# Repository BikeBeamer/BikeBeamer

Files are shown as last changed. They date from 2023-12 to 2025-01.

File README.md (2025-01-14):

# BikeBeamer

## Overview

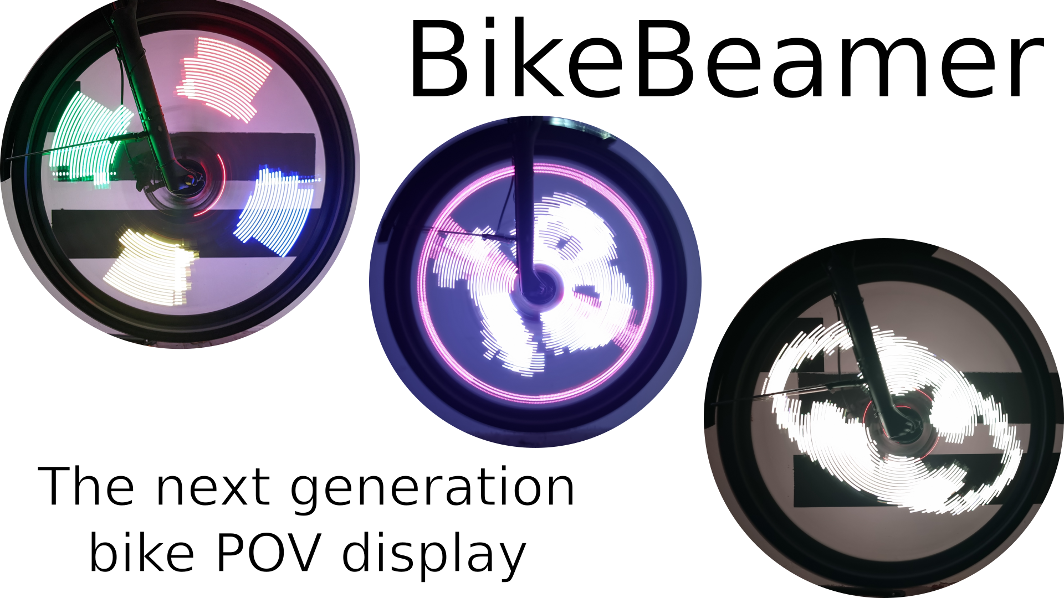
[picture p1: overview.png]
Overview image


This is my next generation of bike POV displays based on [bkpvdsply](https://github.com/locxter/bkpvdsply). With much extended functionality, a more polished design and an easier user-experience, the goal for it is to extend my capabilities and experiment with building a "real product" that lives up to the expectations one might have. Also take a look at the [project website](https://bikebeamer.com) or the launch video:

Introducing BikeBeamer - The next generation bike POV display (https://www.youtube.com/watch?v=l9HWCyl2cUI)

## Dependencies

I generally try to minimize dependencies, but I'm a one man crew and can therefore only support Debian-based Linux distributions as I'm running one myself. Anyway, you need to have the following packages installed for everything to work properly:

- Arduino IDE as a way to compile the Arduino code. Install it with `sudo apt install arduino`.
- MPU6050_tockn library for communicating with the gyroscope. Install it via the integrated library manager.
- Adafruit NeoPixel library for controlling the LEDs. Install it via the integrated library manager.

Note there is an [issue with the ESP32 core library >=3.x and the NeoPixel library when using more than 75 pixels](https://github.com/adafruit/Adafruit_NeoPixel/issues/402). There is a [forked library with a fix](https://github.com/teknynja/Adafruit_NeoPixel/tree/esp32_rmt_memory_allocation_fix_safe).

There some slight differences, depending on which major version of the Arduino IDE you are using. Extensions are not compatible with both versions. An extension is needed for uploading the data to the ESP32 LittleFS.

### Arduino IDE 1.x

Use the Arduino ESP32 LittleFS uploader for uploading the data. Install it via the [installation guide](https://github.com/lorol/arduino-esp32fs-plugin).

### Arduino IDE 2.x

Use the [Arduino LittleFS upload extension](https://github.com/earlephilhower/arduino-littlefs-upload).

## Improvements over bkpvdsply

### Hardware

- [x] Reduce the overall height to fit slimmer wheels
- [x] Rethink the mounting system to be easier for the user
- [x] FAILED: ~~Switch to a reusable cable tie alternative~~
- [x] Improve the water resistance (ideally water proof)
- [x] Make everything more balanced (equal weight distribution)
- [x] Add LED strips to both sides

### Electronics

- [x] Improve battery runtime
- [x] ABANDONED VIA SWITCH TO BATTERIES: ~~Make charging easier~~
- [x] Develop a properly sized power supply unit
- [x] Use custom-made circuit boards
- [ ] Switch to all SMT components
- [ ] Off-hand to production to a specialized vendor

### Software

- [x] Implement customizable LED strip positions (relative to control board)
- [x] Allow the rotation direction to be reversed (when the control board back faces right)
- [x] Use LED trips on both sides to display the image
- [x] Allow the image to be mirrored for the second side (useful for symbols and graphics, but not text)
- [ ] Reduce storage size of images (ideally via file compression)
- [ ] Add the ability to make animations with more than 2 images
- [x] Improve image stability (more exact rotation and speed change detection, smooth measuremets)
- [x] Implement customizable sampling threshold (allowed variation to trigger rotation detection)
- [X] Rework API with clearer endpoints
- [x] Load existing settings to UI for easier incremental changes
- [x] Store and load associative names of images for easier identification

And more to come...

## How to build it

In order to create a device able to produce such wonderful visuals, you only need rather common components (an ESP32, some LED strips, an IMU and some sort of power supply), but their combination results in this really special outcome. Everything is based on a custom PCB onto which all of the other components are soldered and which is then encased in 3D printed parts. Here's what the finished outcome should look like:

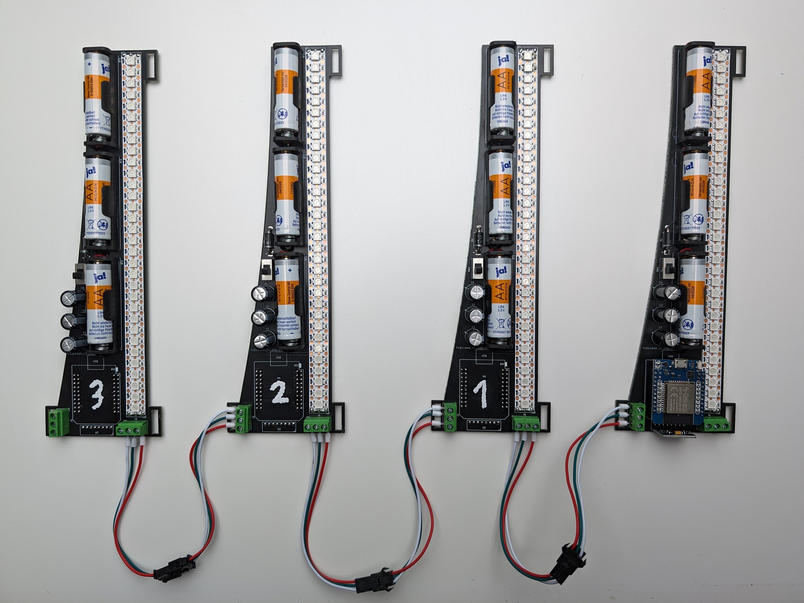
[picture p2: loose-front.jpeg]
Loose boards front


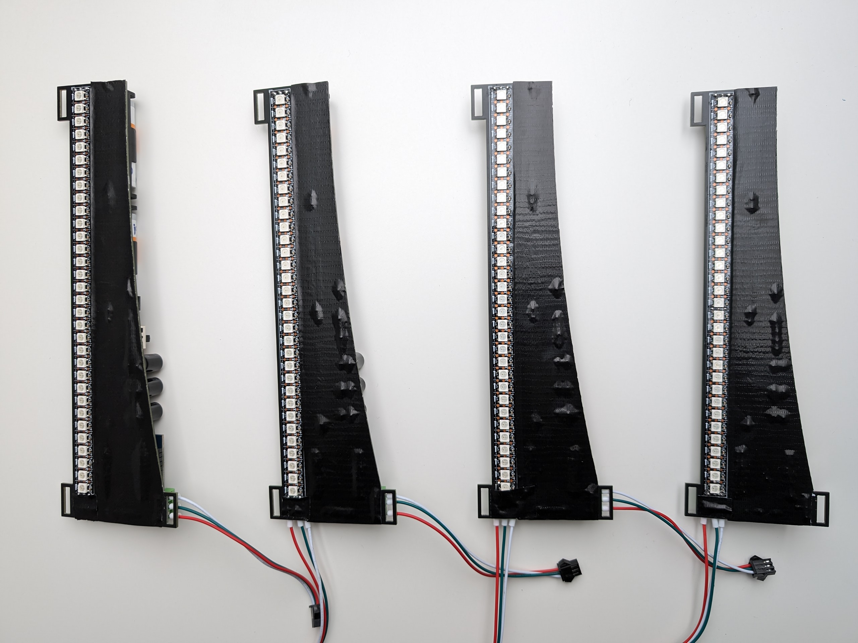
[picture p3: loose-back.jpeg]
Loose boards back


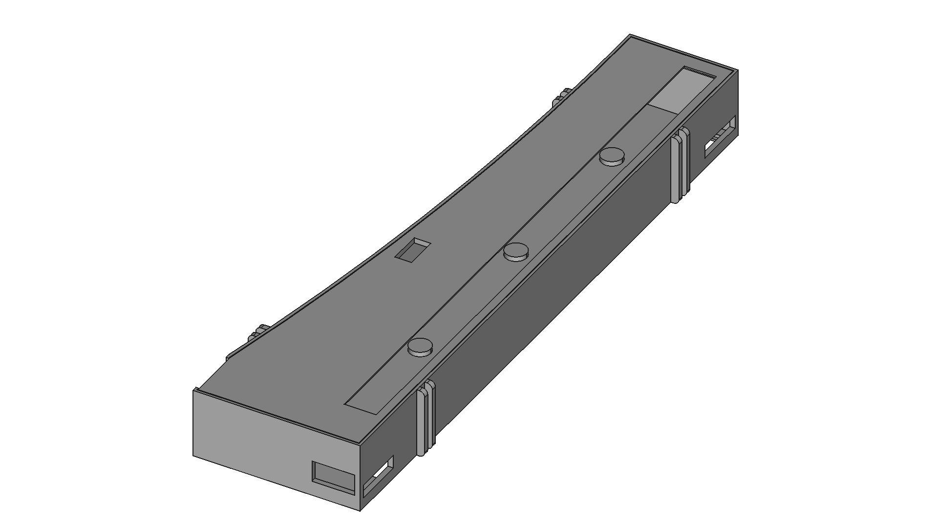
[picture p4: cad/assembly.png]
Case assembly


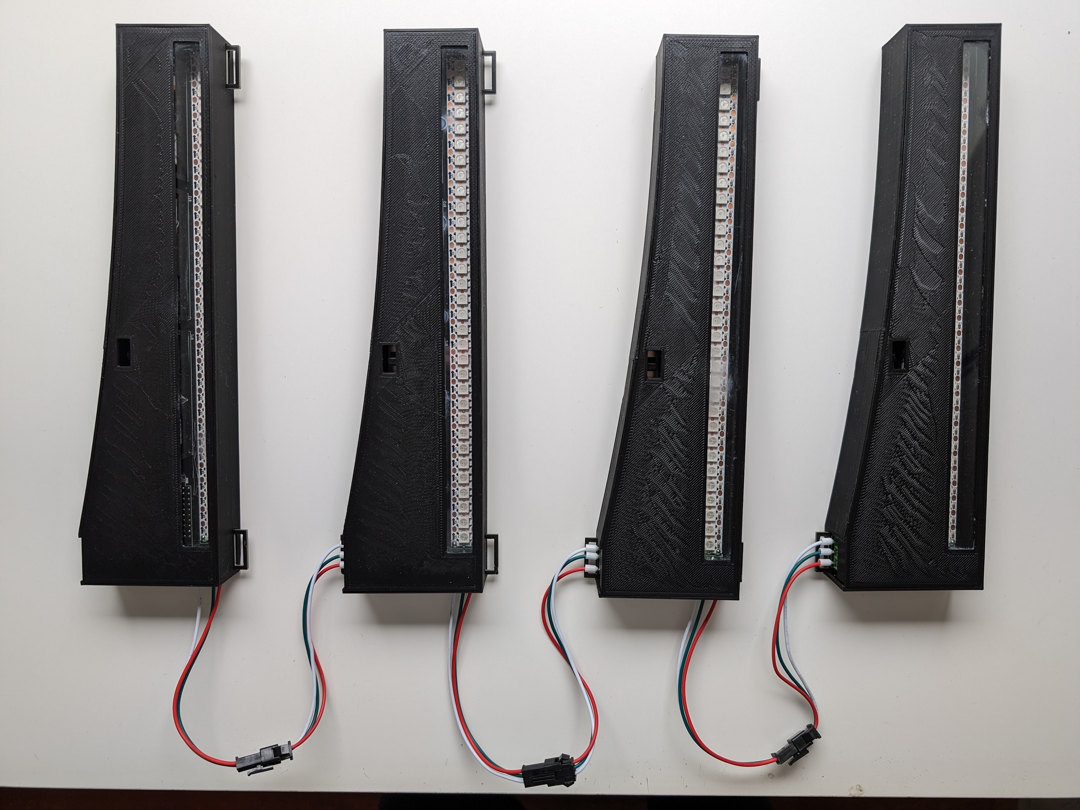
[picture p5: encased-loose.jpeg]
Encased loose boards


Even though many sequences of assembly will result in functional boards, here's how I assemble them after trying out several approaches with varying success:

1. In case you went for the cheap battery holders from Amazon, cut off the brim on the bottom, sand this side for better adhesive contact, shorten the wires and tin them in advance.
2. As always, parts should be soldered in the order of their height. So start off with cutting the LED strips to their desired length of 32 LEDs and then solder them down with the arrows facing towards the slim end of the boards from each side. It's easiest to solder one side of a strip, apply some instant glue along it's way and then solder the other one mounting it into place.
3. After that's done, continue with the diodes - be careful to install them the right way around (silver ring facing the marked direction) - and On/Off switch.
4. Now it's time install the ESP32 and IMU. Solder male headers facing down to the D1 Mini board in case not already done and then mount their female counterparts to the main PCB. You can also fill the contacts on the other boards, but that's not necessary. Then add the right-angle connector to the MPU-6050 board so that it can be mounted vertically to the PCB with its back facing to the wide end of the board and solder it down.
5. You're getting there, just add the screw terminals and then capacitors with the polarity of the latter being crucial (white component markings should face the filled side on the PCB).
6. If necessary glue down the battery holders and then solder them into place - this can be quite tight, but should be doable.
7. To prevent shorts with the spokes from happing isolate the back side with some duck tape or equivalent material. If you want everything to be more moisture resistant, you can also look into spray rubber products.
8. Finally, install the connection cables in the consistent matter and make sure that there are no shorts or other critical mistakes.
9. Once the electronics are done, cut the Plexiglas sheet into 8 14x222mm big pieces, glue them into the 3D prints (4 bottom + 4 top parts) and put them together (bottom part + PCB + top part, 4 times).

Below is a full bill of materials with German sources for all required non-printable parts:

| Quantity (not necessarily the order quantity): | Item: | Source: |
| --- | --- | --- |
| 1 | ESP32 D1 Mini | [Amazon](https://www.amazon.de/dp/B08BTLYSTM) |
| 1 | MPU-6050 | [Amazon](https://www.amazon.de/AZDelivery-MPU-6050-3-Achsen-Gyroskop-Beschleunigungssensor-Arduino/dp/B07TKLYBD6) |
| 2 | LED strip (144 LEDs/m) | [Amazon](https://www.amazon.de/dp/B08JJ6S1HC) |
| 12 | Battery holder | [RS Components](https://de.rs-online.com/web/p/batteriehalter/6119576) OR [Amazon](https://www.amazon.de/AA-Batteriehalter-KUOQIY-Batteriehalter-Drahtkabeln-Schraubendreher/dp/B0C2Q6JV88) |
| 4 | Power switch | [RS Components](https://de.rs-online.com/web/p/schiebeschalter/7347334) OR [Amazon](https://www.amazon.de/RUNCCI-YUN-Schiebeschalter-Positionen-Vertikal-Schalter/dp/B09TVDZ8P2) |
| 12 | Power smoothing capacitor (1000μF) | [RS Components](https://de.rs-online.com/web/p/aluminium-elektrolytkondensatoren/1815420) OR [Amazon](https://www.amazon.de/Kondensator-radial-1000%C2%B5F-RJF-10V102MH4-1000uF/dp/B07H9BFK31) |
| 4 | Reverse-voltage diode (1N5820) | [RS Components](https://de.rs-online.com/web/p/schottky-dioden-und-gleichrichter/6547224) OR [Amazon](https://www.amazon.de/ALLECIN-1N5820-Schottky-Gleichrichterdiode-Siliziumdioden/dp/B0CKSH71TP) |
| 6 | Screw terminal | [RS Components](https://de.rs-online.com/web/p/leiterplatten-printklemmen/1731613) OR [Amazon](https://www.amazon.de/RUNCCI-St%C3%BCcke-Terminal-Schraubklemme-Steckverbinder/dp/B07RR7D267) |
| 6 | JST SM 3 pin cable | [Amazon](https://www.amazon.de/YIXISI-M%C3%A4nnlichen-Weiblichen-Steckverbinder-Elektrisch/dp/B08JV8TJ9N) |
| 12 | AA battery | [Amazon](https://www.amazon.de/Varta-Industrial-Batterie-Alkaline-Batterien-blau/dp/B00LN803LE) |
| 15 | Cable ties | [Amazon](https://www.amazon.de/Kabelbinder-Rscolila-Hochleistungs-Kabelmanagement-300mmx5mm/dp/B09MVKD5YX) |
| 1 | Duck tape | [Amazon](https://www.amazon.de/3M-Gewebeklebeband-1900-Schwarz-1-er/dp/B006MKBVNM) |
| 3 | Instant glue | [Amazon](https://www.amazon.de/Uhu-45415-Sekundenkleber-Blitzschnell-fl%C3%BCssig/dp/B001IVZMBM) |
| 1 | Plexiglas sheet | [Amazon](https://www.amazon.de/Langaelex-transparentes-Plexiglasscheibe-Ersatzglas-Projektausstellung/dp/B0CL93YGQ2) |
| 18 | Wire ferrules | [Amazon](https://www.amazon.de/BAURIX-Aderendh%C3%BClsen-Sortiment-Isolierte-sortiert/dp/B07R6N5MGC) |

## How to use it

1. Build the hardware as described above and put the batteries in.
2. Select the "WEMOS D1 MINI ESP32" board in the Arduino IDE.
3. Flash the sketch with the following settings:
    - `Upload Speed: 9215600`
    - `CPU Frequency: 240MHz (WiFi/BT)`
    - `Flash Frequency: 80MHz`
    - `Partition Scheme: No OTA (Large APP)`
    - `Core Debug Level: None`
    - `Erase All Flash Before Sketch Upload: Disabled`
4. Upload the additional files via the Arduino ESP32 LittleFS uploader.
5. After turning on BikeBeamer, give the ESP roughly half a minute to boot up.
6. Connect to the Wi-Fi network `BikeBeamer`, open any webpage (or `192.168.0.1` if the local DNS server doesn't work) and upload an image (examples are in the `images` folder).
7. Test the assembled hardware on your workbench and check if everything works as expected. Here is some reference footage:

    [Loose boards in action](loose-in-action.mp4)

    https://github.com/user-attachments/assets/22288a13-f305-4ee8-a11e-b3bcc51daa01

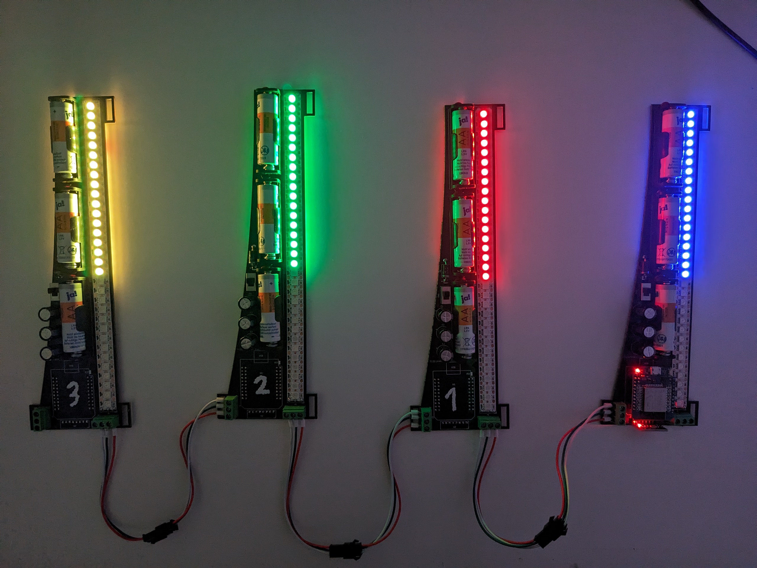
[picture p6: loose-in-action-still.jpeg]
Loose boards in action still
    

8. Mount it on your bike with some cable ties like this:

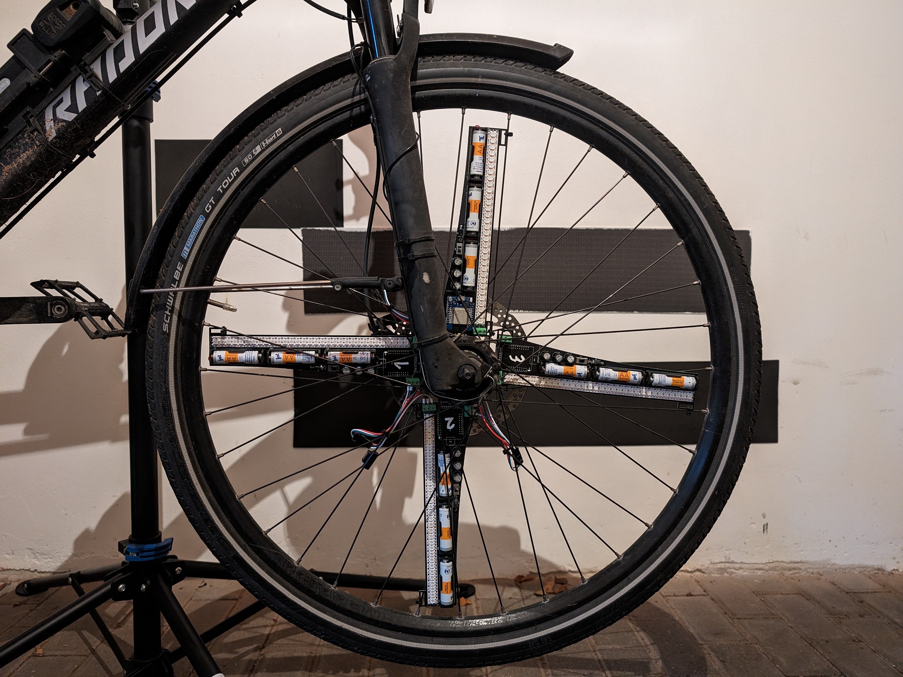
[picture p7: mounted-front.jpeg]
Mounted boards front
    

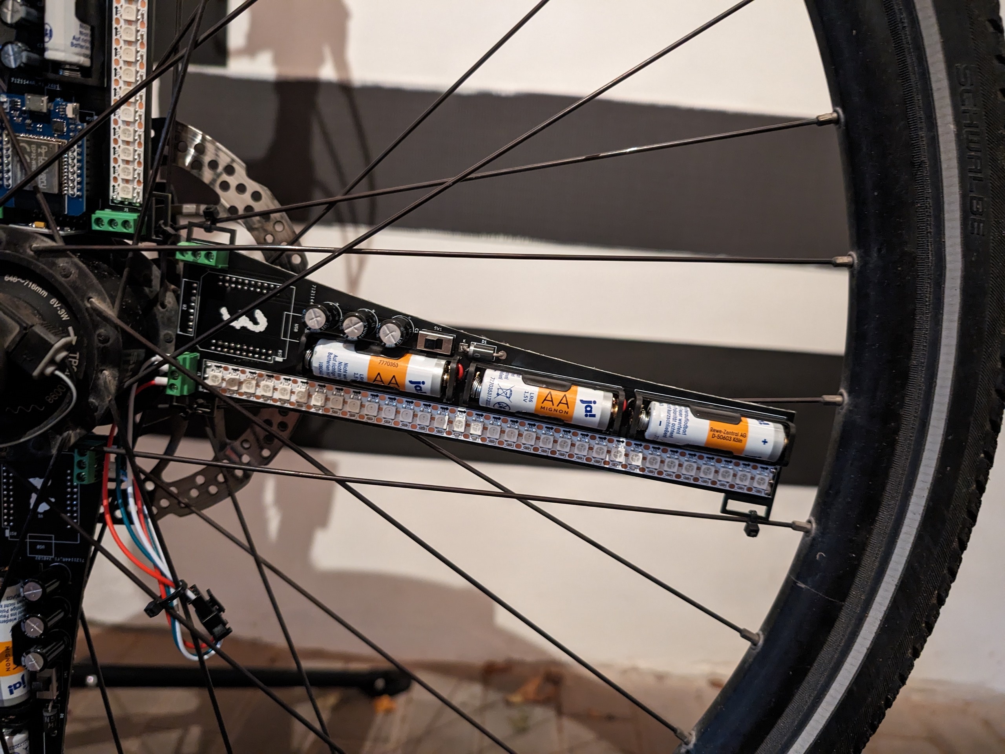
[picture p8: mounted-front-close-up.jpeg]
Mounted boards front close-up
    

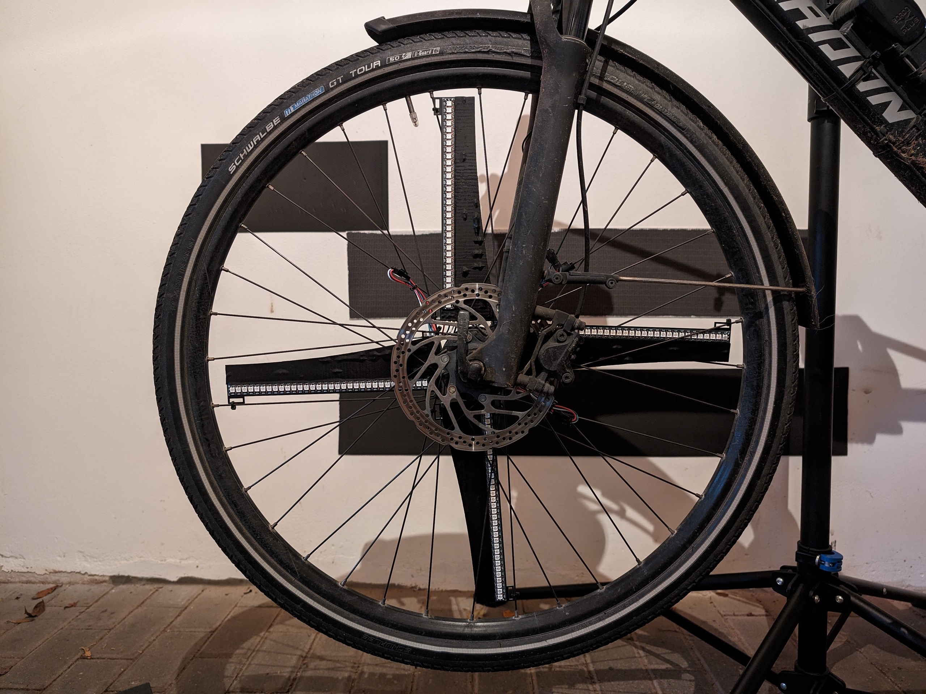
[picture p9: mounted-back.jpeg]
Mounted boards back
    

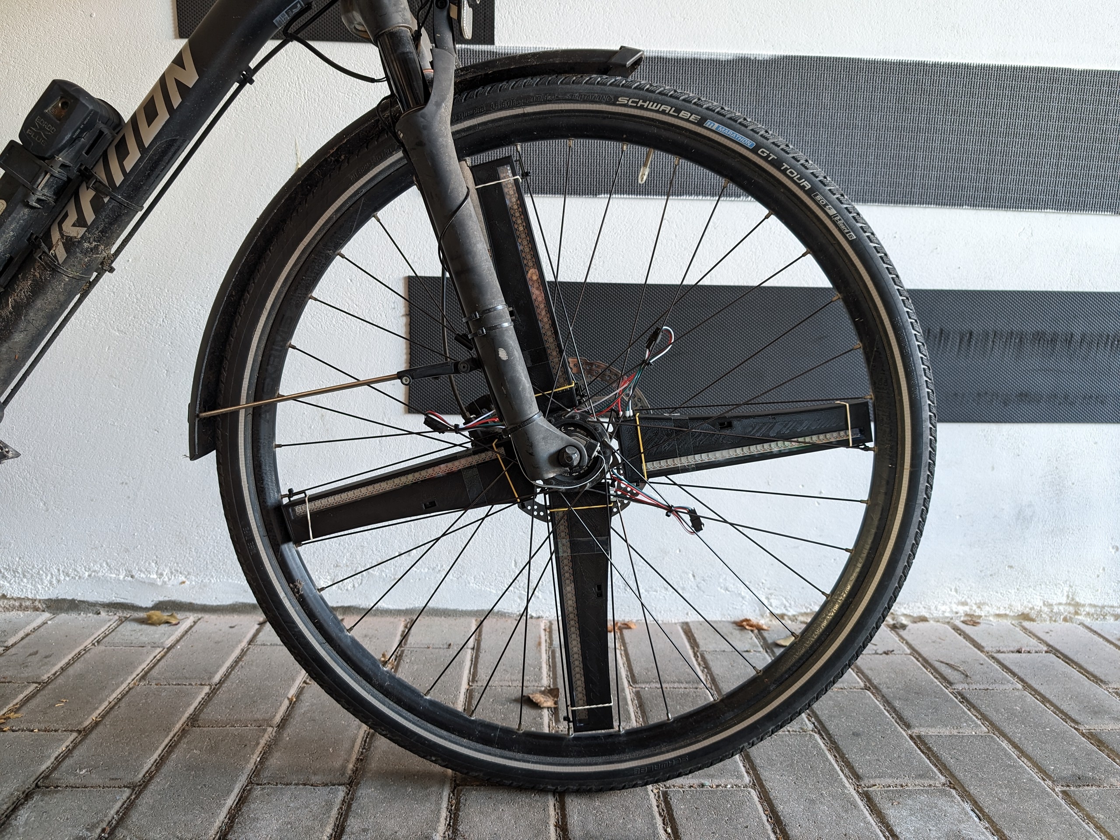
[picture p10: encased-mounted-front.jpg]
Encased mounted boards front
    

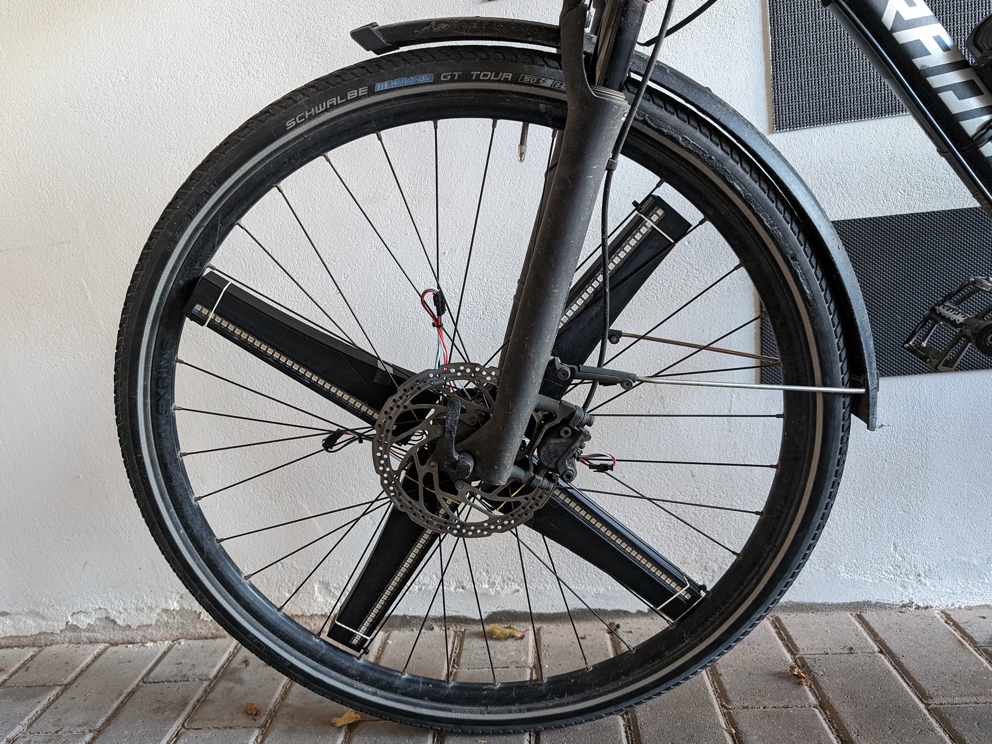
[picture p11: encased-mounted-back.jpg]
Encased mounted boards back
    

9. Then just hop on your bike and enjoy the glory of this next generation POV display. Here's just some inspiration:

    [Mounted boards in action](mounted-in-action.mp4)

    https://github.com/user-attachments/assets/4a3be52c-16f3-4a09-bf7f-77527c5345b7

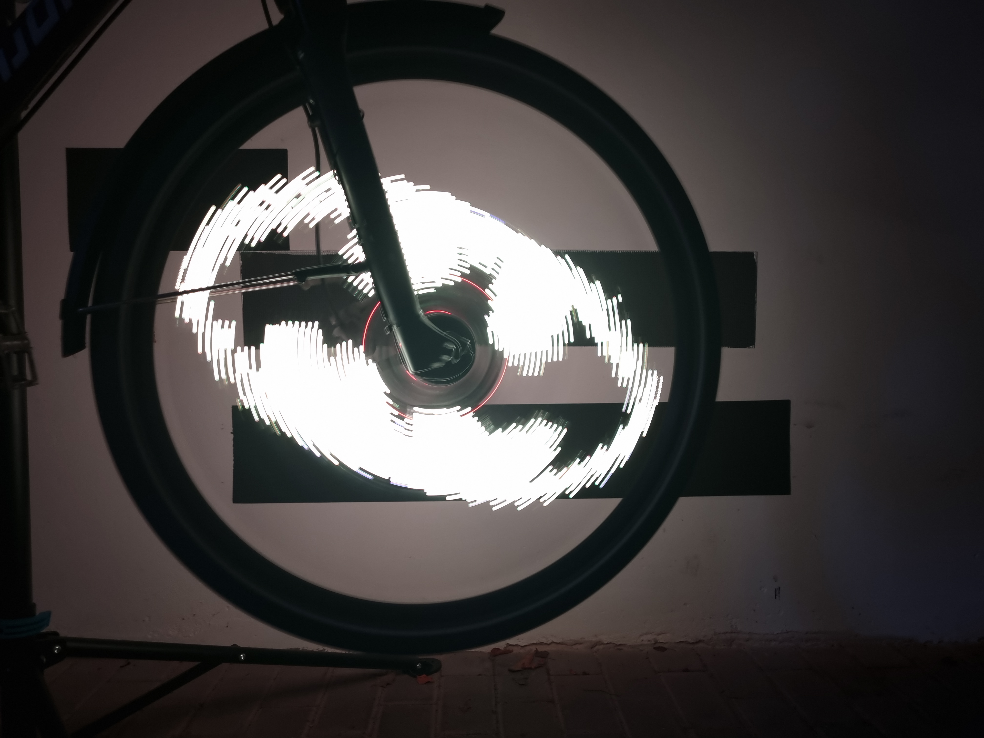
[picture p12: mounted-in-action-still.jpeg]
Mounted boards in action still
    

## Developer notes

- All angles used are in counted in degrees clockwise from 12 o'clock looking at the left side of the bike
- All coordinate systems used have their origin at the bottom left
- The PCBs are mounted with the back side visible when looking at the left side of the bike and connected in clockwise direction
- All indexes in the code are zero-based, while all user interfaces and visualisations use regular one-based numbering
- All API communication is done through HTTP headers for the sake of easy parsing in the front- and backend

### Mounting visualisation

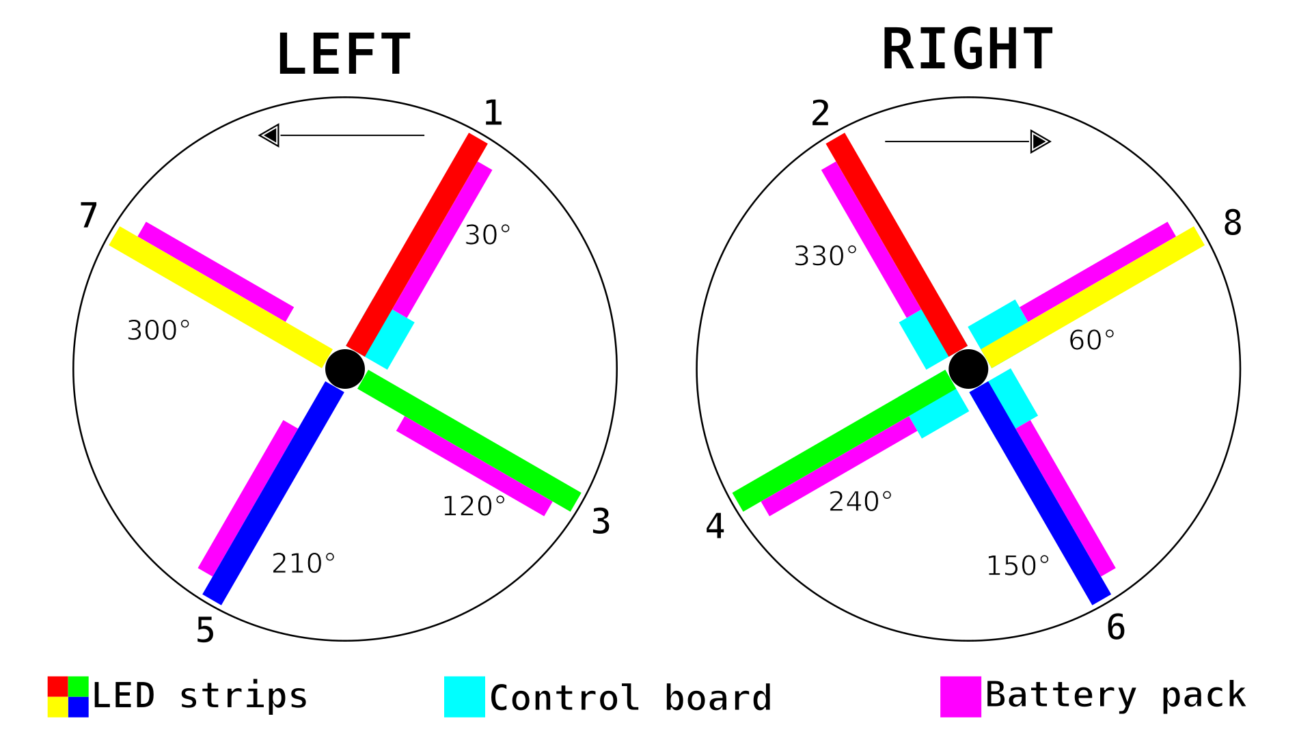
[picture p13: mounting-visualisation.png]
Mounting visualisation


### Image display visualisation

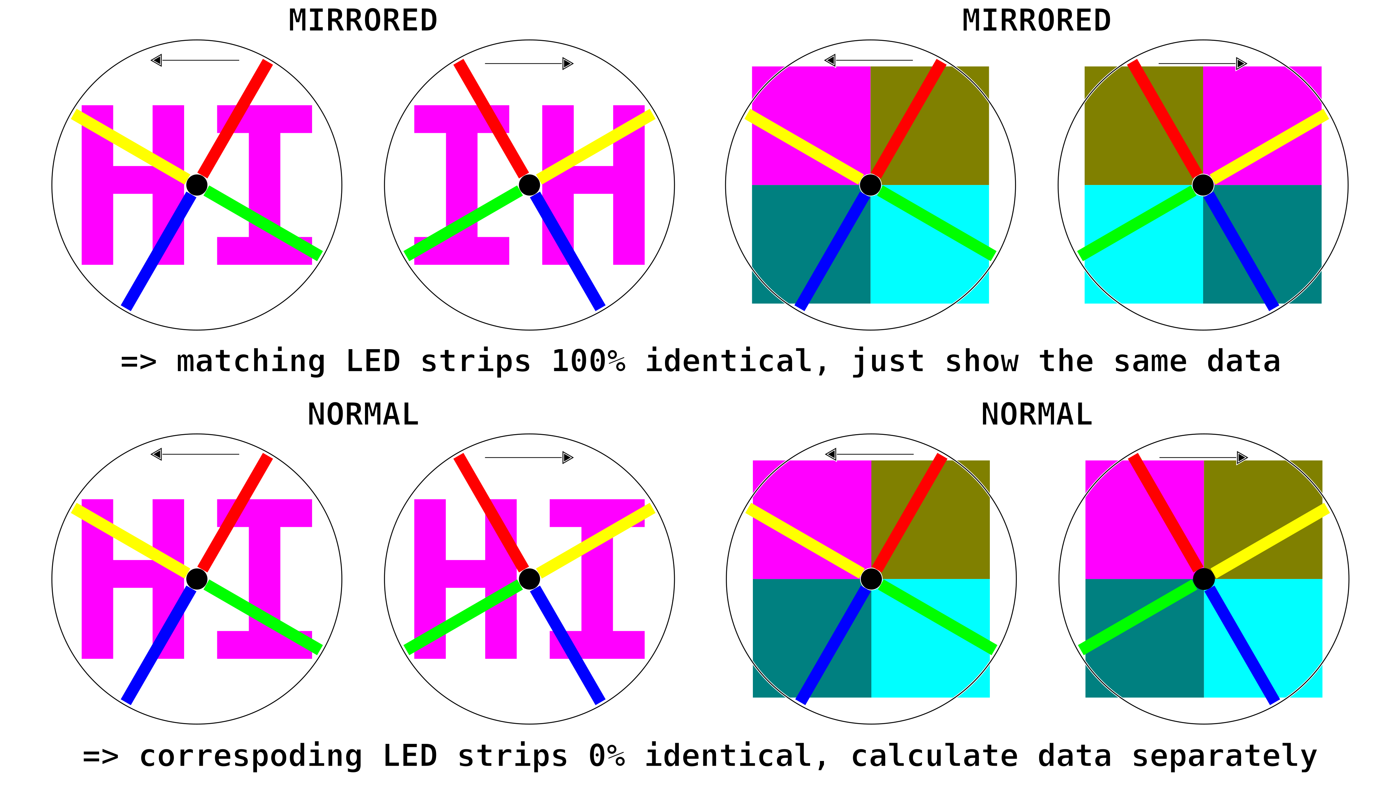
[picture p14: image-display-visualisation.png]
Image display visualidation


### API

- [x] User interface: GET /index.html

#### Settings

- [x] Get stored settings: GET /api/settings
- [X] Update settings: PUT /api/settings

#### Images

- [x] Get image names: GET /api/images
- [X] Update image: PUT /api/images/{slot}

## Similiar projects

- https://subethasoftware.com/bikelights/
- https://www.kickstarter.com/projects/minimonkey/monkey-light-pro-bicycle-wheel-display-system/description
- https://learn.adafruit.com/spokepov/overview
- https://www.ladyada.net/make/spokepov/
- https://learn.adafruit.com/bike-wheel-pov-display/overview
- https://bicycletouringpro.com/hokey-spokes-bicycle-lights-review/

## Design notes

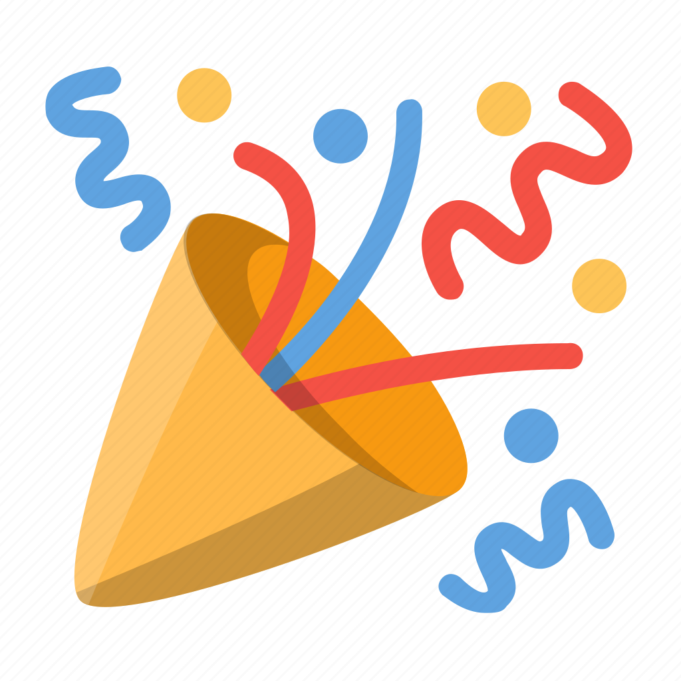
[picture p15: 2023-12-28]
images/celebration.png

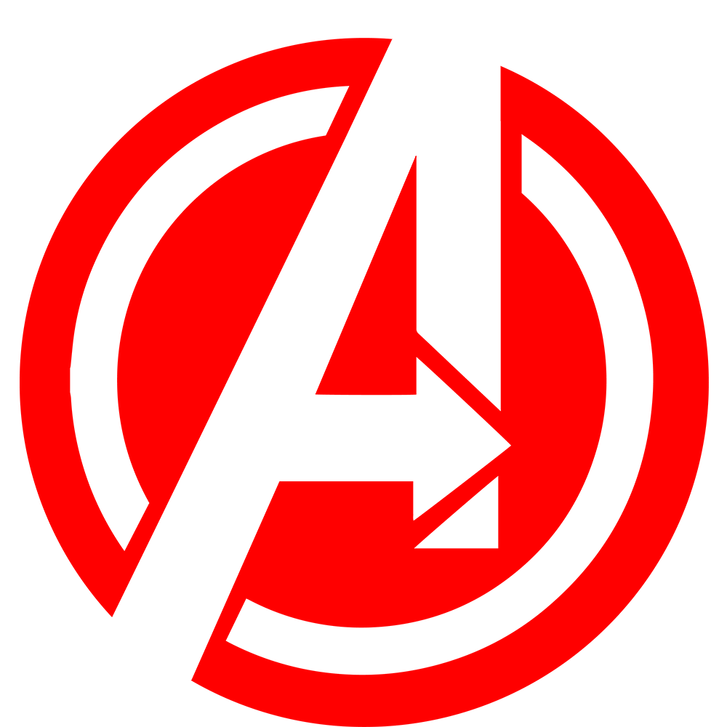
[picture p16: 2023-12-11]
images/avengers.png

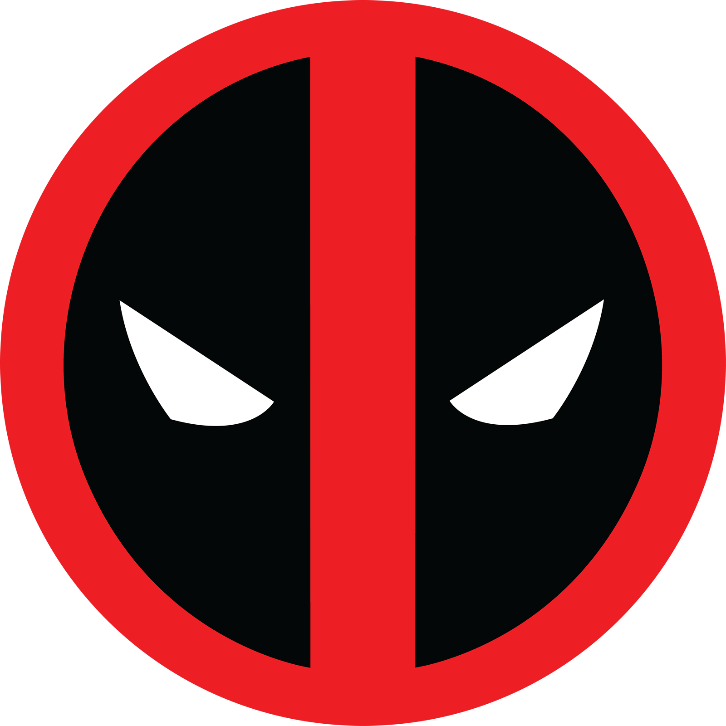
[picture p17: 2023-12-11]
images/deadpool.png

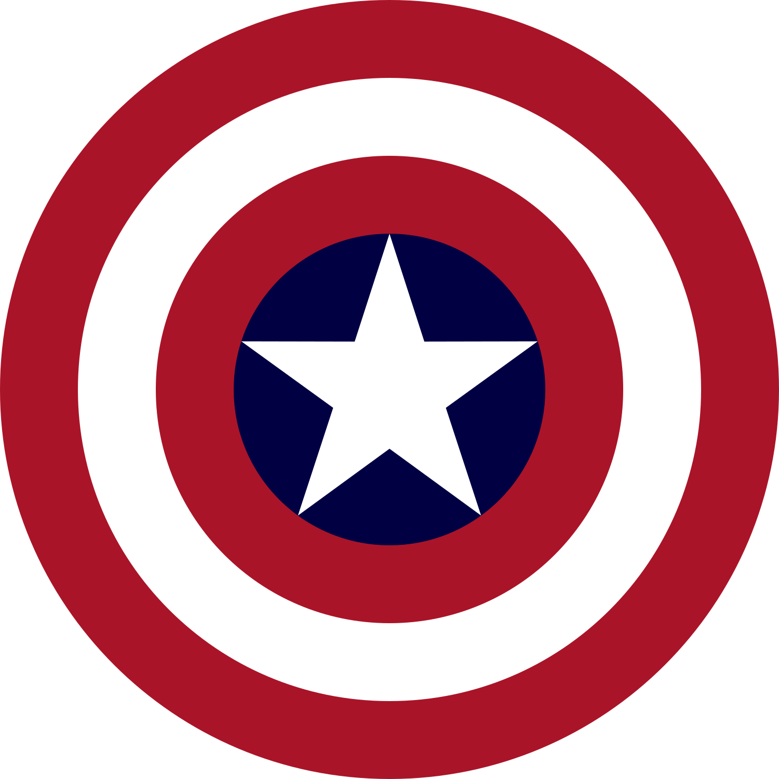
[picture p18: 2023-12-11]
images/captain-america.png

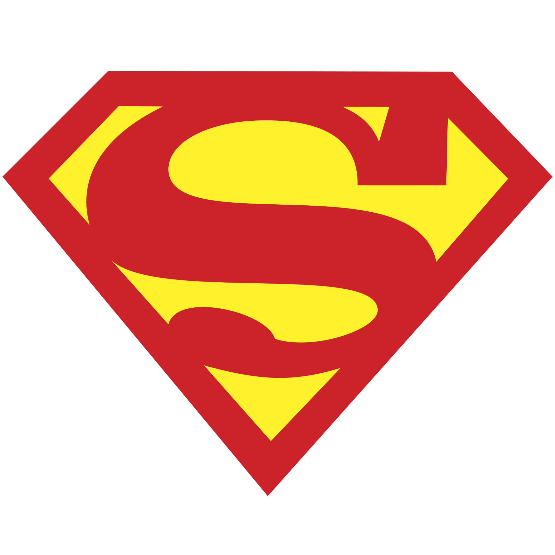
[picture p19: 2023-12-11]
images/superman.png

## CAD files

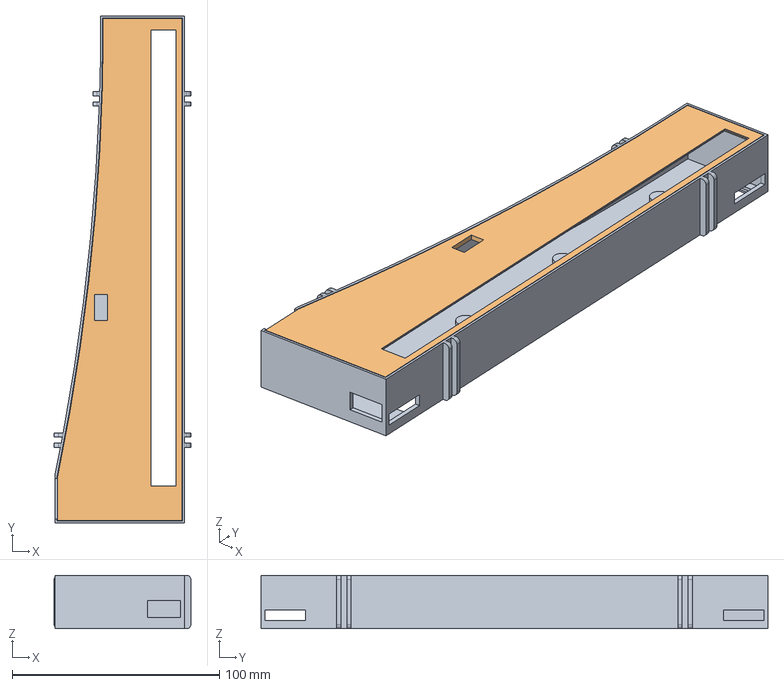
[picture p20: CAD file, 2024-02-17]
cad/bikebeamer-v0.2/assembly.FCStd
65.9 x 244.5 x 25.8 mm
case-bottom_001
case-top_001

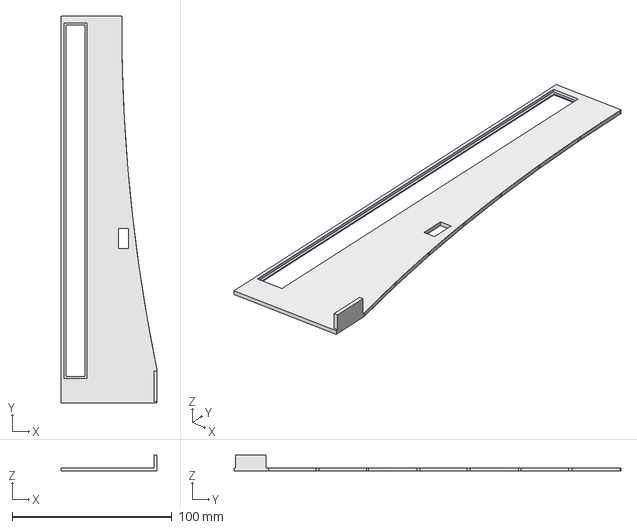
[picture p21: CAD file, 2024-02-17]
cad/bikebeamer-v0.2/case-top.FCStd
60.0 x 242.0 x 10.0 mm
Body (Meshed)

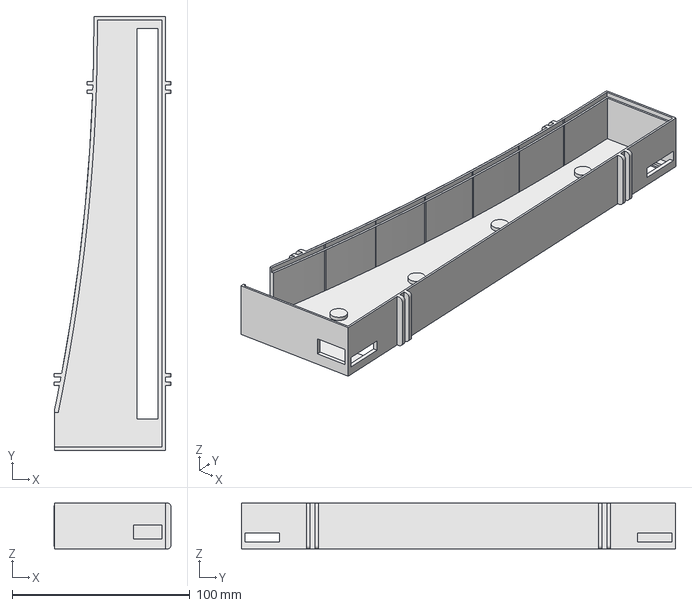
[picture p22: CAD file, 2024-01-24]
cad/bikebeamer-v0.2/case-bottom.FCStd
65.9 x 244.5 x 25.8 mm
Body (Meshed)

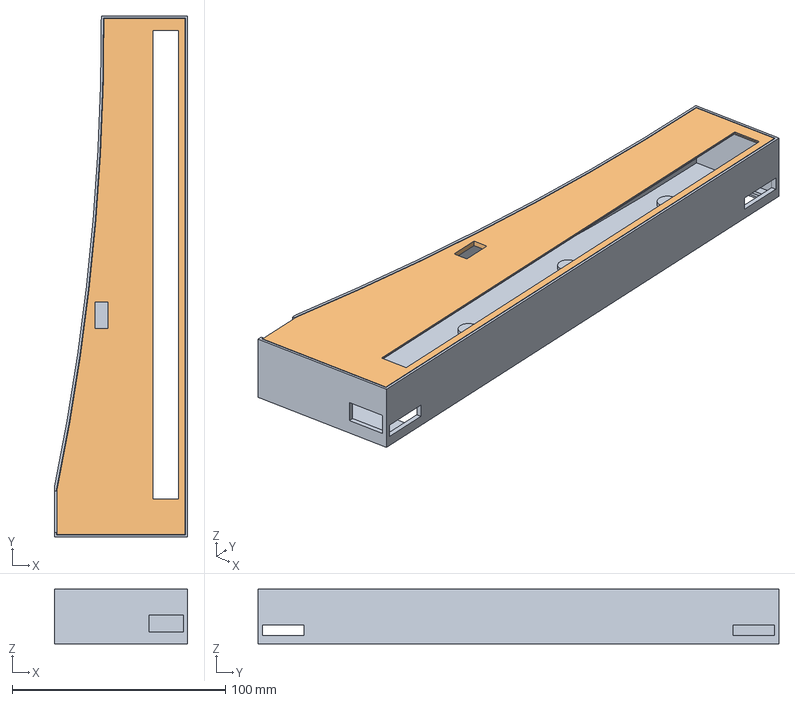
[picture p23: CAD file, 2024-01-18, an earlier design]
cad/bikebeamer-v0.1/assembly.FCStd
62.5 x 244.5 x 25.8 mm
case-bottom_001
case-top_001

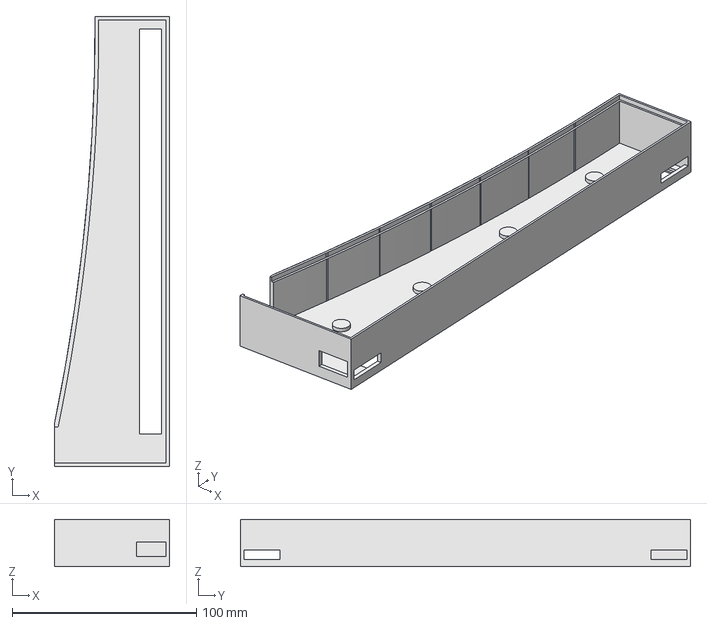
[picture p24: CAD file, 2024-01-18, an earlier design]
cad/bikebeamer-v0.1/case-bottom.FCStd
62.5 x 244.5 x 25.8 mm
Body (Meshed)

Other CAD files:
cad/bikebeamer-v0.1/case-top.FCStd
cad/bikebeamer-v0.1/case-bottom.stl
cad/bikebeamer-v0.1/case-top.stl
cad/bikebeamer-v0.2/case-bottom.stl
cad/bikebeamer-v0.2/case-top.stl

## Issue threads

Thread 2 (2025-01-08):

Board rebooting

simonemarin, 2025-01-08:
I have uploaded the code but I get a rebooting board with error:
```
E (2461) esp_littlefs: mount failed,  (-84)
E (2465) esp_littlefs: Failed to initialize LittleFS
```
Questions:

- will a ESP32 Wroom 32 board work instead of the Wemos Mini?
- is the No Ota 2/2 spiffs partition scheme ok?
- may it be the issue that I haven t got yet a gyroscope connected?

simonemarin, 2025-01-13:
I tried another PC and it loaded correctly, same IDE same libraries, not sure why it happens

locxter, 2025-01-14:
Glad you got it working - sorry for not responding, I was quite busy the last few days. If you have any further issues, feel free to reach out :)

Closed 2025-01-13.

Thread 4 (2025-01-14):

New PCB for 18650 batteries

simonemarin, 2025-01-14:
I happen to have a bunch of 18650 batteries and used them for other projects, they do have a better capacity and can be recharged so they may be a better choice for this project. Instead of reinventing the wheel I got a UPS/charger module from Aliexpress: https://es.aliexpress.com/item/1005004863984398.html
Here a preview of the new PCB, all the battery block was subsittuted for a simple J3 connector that connects to the module with a JST HX:
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

locxter, 2025-01-15:
Great idea, definitely let me know if it works - would be a huge upgrade to the current solution, which is mostly the result of lazyness :)
Regarding the attributions, I don't mind you changing them a bit, but would be glad if atleast my username stays somewhere - I hope that's understandable

simonemarin, 2025-01-23:
This is what I have come up with, I am still waiting for some connectors and the wemos but this may be something quite finished:
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

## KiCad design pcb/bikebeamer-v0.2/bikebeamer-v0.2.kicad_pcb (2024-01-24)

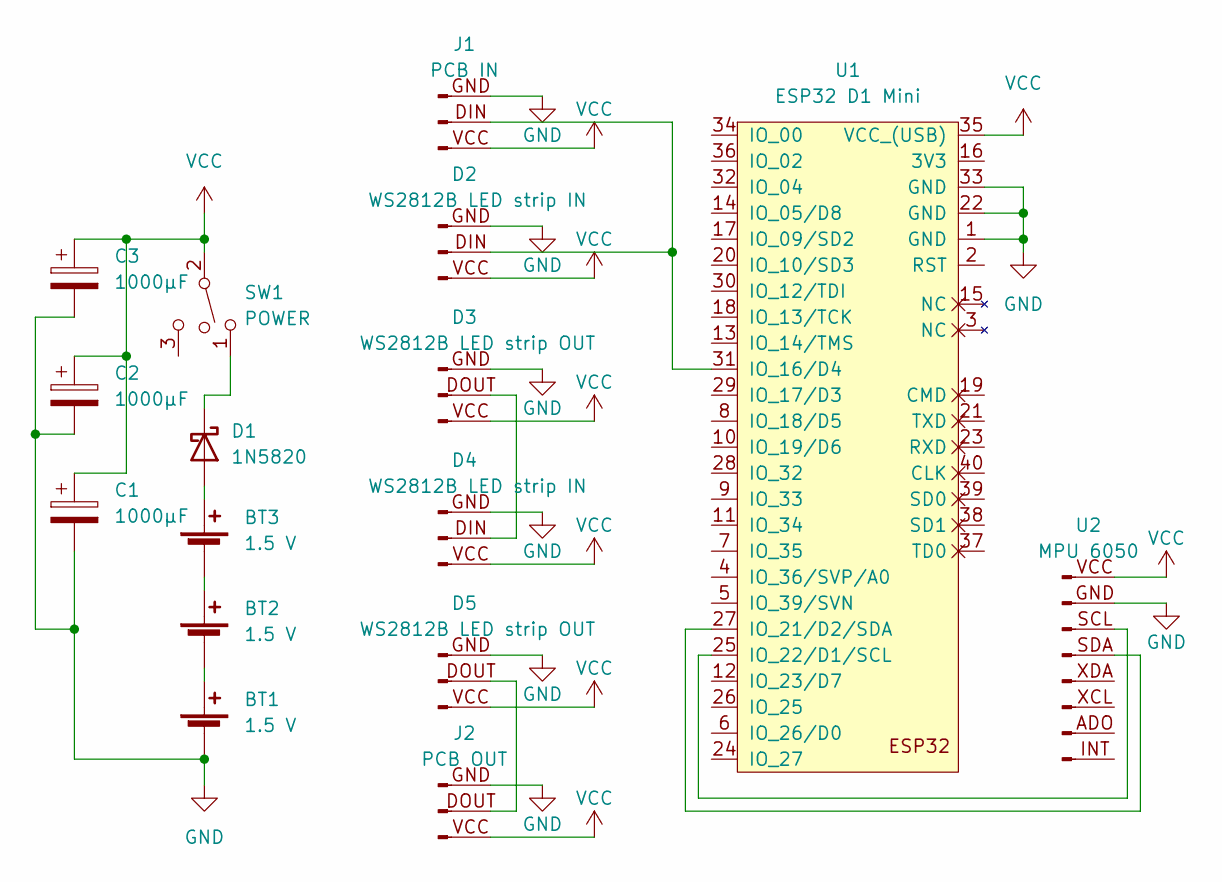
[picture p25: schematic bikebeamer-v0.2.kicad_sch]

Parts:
BT1, BT2, BT3: 1.5 V; BatteryHolder_Keystone_2460_1xAA
C1, C2, C3: 1000µF; CP_Radial_D10.0mm_P5.00mm
D1: 1N5820; D_DO-201AD_P15.24mm_Horizontal
D2, D4: WS2812B LED strip IN; PhoenixContact_MCV_1,5_3-G-5.08_1x03_P5.08mm_Vertical
D3, D5: WS2812B LED strip OUT; PhoenixContact_MCV_1,5_3-G-5.08_1x03_P5.08mm_Vertical
J1: PCB IN; PhoenixContact_MCV_1,5_3-G-5.08_1x03_P5.08mm_Vertical
J2: PCB OUT; PhoenixContact_MCV_1,5_3-G-5.08_1x03_P5.08mm_Vertical
SW1: POWER; SW_Slide_1P2T_CK_OS102011MS2Q
U1: ESP32 D1 Mini; ESP32_mini
U2: MPU 6050; PinHeader_1x08_P2.54mm_Vertical

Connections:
GND: BT1.2 (-), C1.2, C2.2, C3.2, D2.GND (Pin_1), D3.GND (Pin_1), D4.GND (Pin_1), D5.GND (Pin_1), J1.GND (Pin_1), J2.GND (Pin_1), U1.1 (GND), U1.22 (GND), U1.33 (GND), U2.GND (Pin_2)
unnamed: BT1.1 (+), BT2.2 (-)
unnamed: BT2.1 (+), BT3.2 (-)
unnamed: BT3.1 (+), D1.2 (A)
unnamed: D1.1 (K), SW1.1
unnamed: D2.DIN (Pin_2), J1.DIN (Pin_2), U1.31 (IO_16/D4)
unnamed: D3.DOUT (Pin_2), D4.DIN (Pin_2)
unnamed: D5.DOUT (Pin_2), J2.DOUT (Pin_2)
unnamed: U1.25 (IO_22/D1/SCL), U2.SCL (Pin_3)
unnamed: U1.27 (IO_21/D2/SDA), U2.SDA (Pin_4)
VCC: C1.1, C2.1, C3.1, D2.VCC (Pin_3), D3.VCC (Pin_3), D4.VCC (Pin_3), D5.VCC (Pin_3), J1.VCC (Pin_3), J2.VCC (Pin_3), SW1.2, U1.35 (VCC_(USB)), U2.VCC (Pin_1)

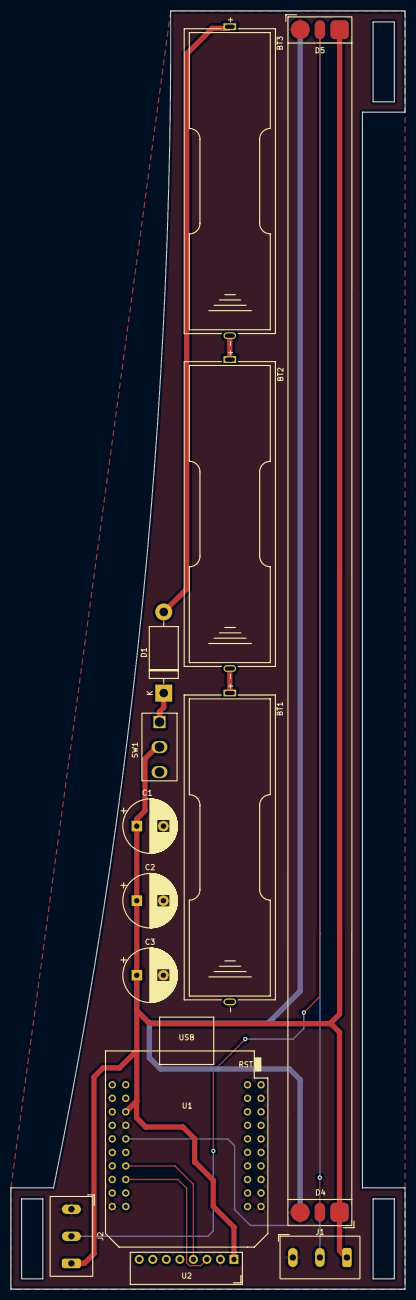
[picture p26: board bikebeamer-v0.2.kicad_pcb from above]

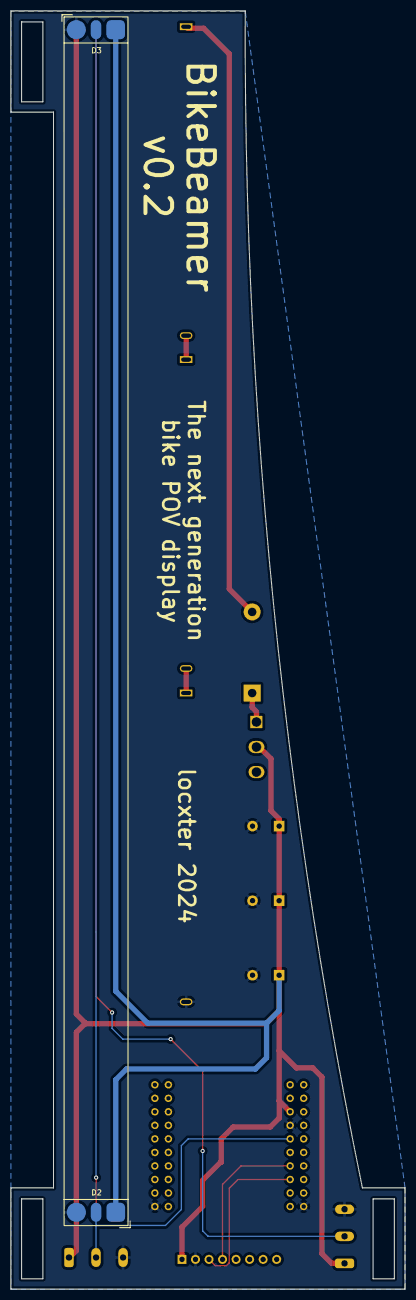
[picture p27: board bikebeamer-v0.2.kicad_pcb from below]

Board: 2 copper layers, 74.0 x 240.0 mm, 16 parts (2 on the bottom side), 11 nets.

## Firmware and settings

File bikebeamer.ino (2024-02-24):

#include <Adafruit_NeoPixel.h>
#include <DNSServer.h>
#include <LittleFS.h>
#include <MPU6050_tockn.h>
#include <WebServer.h>
#include <WiFi.h>
#include <WiFiClient.h>
#include <Wire.h>
#include <uri/UriBraces.h>

// LED and WiFi related constants
const int NEOPIXELS_PIN = 16;
const int STORAGE_SLOT_COUNT = 8;
const int LED_COUNT = 32;
const char* SSID = "BikeBeamer";
const char* WIFI_PASSWORD = "BikeBeamer";
const IPAddress IP(192, 168, 0, 1);

// MPU, NeoPixel and server objects
MPU6050 mpu(Wire);
Adafruit_NeoPixel neopixels(LED_COUNT * 8, NEOPIXELS_PIN, NEO_GRB + NEO_KHZ800);
DNSServer dns;
WebServer server(80);

// Other variables
byte images[2][360 * LED_COUNT][3];
int brightness = 51;
bool mirrorImage = true;
int displayMode = 0;
unsigned long animationInterval = 1000000;
int internalWheelDiameter = 600;
int hubDiameter = 80;
int strip1Position = 90;
int strip2Position = 180;
int strip3Position = 270;
int samplingThreshold = 8;
int sampleCount = 1;
int avgdRevolutionPeriods = 80;
unsigned long currentMicros = 0;
unsigned long revolutionPeriod = 0;
unsigned long lastSample = 0;
unsigned long lastSlotChange = 0;
int currentMemorySlot = 0;
int angle = 0;
int virtualAngle = 0;
int lastVirtualAngle = -1;
bool isReceiving = false;
bool isPaused = true;
unsigned long revolutionOffset = 0;
unsigned long oldRevolutionPeriods[99];
int emptyRevolutionPeriods = 0;
unsigned long avgRevolutionPeriod = 0;

// Function to load the settings from storage into RAM
void loadSettings();

// Function to load an image from storage into RAM
void loadImage(int storageSlot, int memorySlot);

// Function to save the settings from RAM into storage
void saveSettings();

// Function to save an image name into storage
void saveImageName(int storageSlot, String newName);

// Setup function
void setup() {
    // Confirm successful boot
    pinMode(LED_BUILTIN, OUTPUT);
    digitalWrite(LED_BUILTIN, HIGH);
    delay(500);
    digitalWrite(LED_BUILTIN, LOW);
    delay(500);
    // Initialize MPU
    Wire.begin();
    mpu.begin();
    mpu.calcGyroOffsets();
    // Initialize filesystem and memory
    LittleFS.begin();
    loadSettings();
    if (displayMode < STORAGE_SLOT_COUNT) {
        loadImage(displayMode, 0);
    } else {
        loadImage(displayMode - STORAGE_SLOT_COUNT, 0);
        loadImage((displayMode - (STORAGE_SLOT_COUNT - 1)) % STORAGE_SLOT_COUNT, 1);
    }
    // Initiliaze NeoPixels
    neopixels.begin();
    neopixels.setBrightness(brightness);
    neopixels.clear();
    neopixels.show();
    // Initialize WiFi network
    WiFi.mode(WIFI_AP);
    WiFi.softAPConfig(IP, IP, IPAddress(255, 255, 255, 0));
    WiFi.softAP(SSID, WIFI_PASSWORD);
    // Initialize DNS
    dns.start(53, "*", IP);
    // Initialize web server
    server.enableCORS(true);
    server.on("/api/settings", HTTP_GET, [&]() {
        server.sendHeader("brightness", String(brightness));
        server.sendHeader("mirror-image", String(mirrorImage));
        server.sendHeader("display-mode", String(displayMode));
        server.sendHeader("animation-interval", String(animationInterval));
        server.sendHeader("internal-wheel-diameter", String(internalWheelDiameter));
        server.sendHeader("hub-diameter", String(hubDiameter));
        server.sendHeader("strip-1-position", String(strip1Position));
        server.sendHeader("strip-2-position", String(strip2Position));
        server.sendHeader("strip-3-position", String(strip3Position));
        server.sendHeader("sampling-threshold", String(samplingThreshold));
        server.sendHeader("sample-count", String(sampleCount));
        server.sendHeader("averaged-revolution-periods", String(avgdRevolutionPeriods));
        server.send(200);
    });
    server.on("/api/settings", HTTP_PUT, [&]() {
        // Check for necessary arguments
        bool hasSettingsArgs = server.hasArg("brightness") && server.hasArg("mirror-image") &&
                               server.hasArg("display-mode") && server.hasArg("animation-interval") &&
                               server.hasArg("internal-wheel-diameter") && server.hasArg("hub-diameter") &&
                               server.hasArg("strip-1-position") && server.hasArg("strip-2-position") &&
                               server.hasArg("strip-3-position") && server.hasArg("sampling-threshold") &&
                               server.hasArg("sample-count") && server.hasArg("averaged-revolution-periods");
        // Extract and store the received data
        if (hasSettingsArgs) {
            isReceiving = true;
            neopixels.clear();
            neopixels.show();
            for (int i = 0; i < avgdRevolutionPeriods - 1; i++) {
                oldRevolutionPeriods[i] = 0;
            }
            brightness = server.arg("brightness").toInt();
            mirrorImage = server.arg("mirror-image").toInt();
            displayMode = server.arg("display-mode").toInt();
            animationInterval = server.arg("animation-interval").toInt();
            internalWheelDiameter = server.arg("internal-wheel-diameter").toInt();
            hubDiameter = server.arg("hub-diameter").toInt();
            strip1Position = server.arg("strip-1-position").toInt();
            strip2Position = server.arg("strip-2-position").toInt();
            strip3Position = server.arg("strip-3-position").toInt();
            samplingThreshold = server.arg("sampling-threshold").toInt();
            sampleCount = server.arg("sample-count").toInt();
            avgdRevolutionPeriods = server.arg("averaged-revolution-periods").toInt();
            neopixels.setBrightness(brightness);
            neopixels.show();
            if (displayMode < STORAGE_SLOT_COUNT) {
                loadImage(displayMode, currentMemorySlot);
            } else {
                loadImage(displayMode - STORAGE_SLOT_COUNT, 0);
                loadImage((displayMode - (STORAGE_SLOT_COUNT - 1)) % STORAGE_SLOT_COUNT, 1);
            }
            saveSettings();
            isReceiving = false;
            server.send(200);
        } else {
            server.send(404, "text/plain", "Invalid request");
        }
    });
    server.on("/api/images", HTTP_GET, [&]() {
        File file = LittleFS.open("/data/images.csv", "r");
        while (file.available()) {
            String line = file.readStringUntil('\n');
            String slot = line.substring(0, line.indexOf(','));
            int slotInt = slot.toInt();
            line.remove(0, line.indexOf(',') + 2);
            String name = line;
            if (slot.length() <= String(STORAGE_SLOT_COUNT).length() && slotInt >= 0 && slotInt < STORAGE_SLOT_COUNT) {
                server.sendHeader("slot-" + slot, name);
            }
        }
        file.close();
        server.send(200);
    });
    server.on(UriBraces("/api/images/{}"), HTTP_PUT, []() {
        // Check for necessary arguments
        bool hasImageArgs = server.pathArg(0).length() > 0 && server.pathArg(0).toInt() >= 0 &&
                            server.pathArg(0).toInt() < STORAGE_SLOT_COUNT && server.hasArg("name") &&
                            server.hasArg("angle");
        for (int i = 0; i < LED_COUNT; i++) {
            if (!hasImageArgs) {
                break;
            }
            hasImageArgs = server.hasArg("led-" + String(i) + "-r");
        }
        for (int i = 0; i < LED_COUNT; i++) {
            if (!hasImageArgs) {
                break;
            }
            hasImageArgs = server.hasArg("led-" + String(i) + "-g");
        }
        for (int i = 0; i < LED_COUNT; i++) {
            if (!hasImageArgs) {
                break;
            }
            hasImageArgs = server.hasArg("led-" + String(i) + "-b");
        }
        // Extract and store the received data
        if (hasImageArgs) {
            int storageSlot = server.pathArg(0).toInt();
            int memorySlot = -1;
            int angle = server.arg("angle").toInt();
            String filename = "/data/image-" + String(storageSlot) + ".csv";
            File file;
            if (angle == 0) {
                isReceiving = true;
                neopixels.clear();
                neopixels.show();
                for (int i = 0; i < avgdRevolutionPeriods - 1; i++) {
                    oldRevolutionPeriods[i] = 0;
                }
                saveImageName(storageSlot, server.arg("name"));
                file = LittleFS.open(filename, "w");
                file.print("R:, G:, B:\n");
            } else {
                file = LittleFS.open(filename, "a");
            }
            if (storageSlot == displayMode) {
                memorySlot = currentMemorySlot;
            } else if (storageSlot == displayMode - STORAGE_SLOT_COUNT) {
                memorySlot = 0;
            } else if (storageSlot == (displayMode - (STORAGE_SLOT_COUNT - 1)) % STORAGE_SLOT_COUNT) {
                memorySlot = 1;
            }
            for (int i = 0; i < LED_COUNT; i++) {
                byte r = server.arg("led-" + String(i) + "-r").toInt();
                byte g = server.arg("led-" + String(i) + "-g").toInt();
                byte b = server.arg("led-" + String(i) + "-b").toInt();
                if (memorySlot != -1) {
                    images[memorySlot][(angle * LED_COUNT) + i][0] = r;
                    images[memorySlot][(angle * LED_COUNT) + i][1] = g;
                    images[memorySlot][(angle * LED_COUNT) + i][2] = b;
                }
                file.print(String(r) + ", " + String(g) + ", " + String(b) + "\n");
            }
            file.close();
            if (angle == 359) {
                isReceiving = false;
            }
            server.send(200);
        } else {
            server.send(404, "text/plain", "Invalid request");
        }
    });
    server.serveStatic("/", LittleFS, "/index.html");
    server.serveStatic("/index.html", LittleFS, "/index.html");
    server.serveStatic("/data/image-0.csv", LittleFS, "/data/image-0.csv");
    server.serveStatic("/data/image-1.csv", LittleFS, "/data/image-1.csv");
    server.serveStatic("/data/image-2.csv", LittleFS, "/data/image-2.csv");
    server.serveStatic("/data/image-3.csv", LittleFS, "/data/image-3.csv");
    server.serveStatic("/data/image-4.csv", LittleFS, "/data/image-4.csv");
    server.serveStatic("/data/image-5.csv", LittleFS, "/data/image-5.csv");
    server.serveStatic("/data/image-6.csv", LittleFS, "/data/image-6.csv");
    server.serveStatic("/data/image-7.csv", LittleFS, "/data/image-7.csv");
    server.serveStatic("/data/images.csv", LittleFS, "/data/images.csv");
    server.serveStatic("/data/settings.csv", LittleFS, "/data/settings.csv");
    server.serveStatic("/scripts/index.js", LittleFS, "/scripts/index.js");
    server.serveStatic("/styles/dark.min.css", LittleFS, "/styles/dark.min.css");
    server.onNotFound([&]() {
        server.send(404, "text/plain", "Resource not found");
    });
    server.begin();
    lastSample = micros();
    lastSlotChange = micros();
}

// Main function
void loop() {
    if (!isReceiving) {
        mpu.update();
        angle = ((int) round(mpu.getAccAngleX()) + 360) % 360;
        currentMicros = micros();
        // Calculate revolution period and update other data on every rotation when the user is pedalling
        if ((angle >= (360 - samplingThreshold) || angle <= samplingThreshold) &&
            ((sampleCount == 0 && currentMicros - lastSample >= 150000 && currentMicros - lastSample <= 1500000) ||
             (sampleCount == 1 && currentMicros - lastSample >= 75000 && currentMicros - lastSample <= 750000) ||
             (sampleCount == 2 && currentMicros - lastSample >= 37500 && currentMicros - lastSample <= 375000))) {
            if (isPaused) {
                isPaused = false;
            }
            switch (sampleCount) {
                case 0:
                    revolutionPeriod = currentMicros - lastSample;
                    break;
                case 1:
                    revolutionPeriod = (currentMicros - lastSample) * 2;
                    break;
                case 2:
                    revolutionPeriod = (currentMicros - lastSample) * 4;
                    break;
            }
            avgRevolutionPeriod = revolutionPeriod;
            emptyRevolutionPeriods = 0;
            for (int i = 0; i < avgdRevolutionPeriods - 1; i++) {
                avgRevolutionPeriod += oldRevolutionPeriods[i];
                if (oldRevolutionPeriods[i] == 0) {
                    emptyRevolutionPeriods++;
                }
            }
            avgRevolutionPeriod =
                (unsigned long) round(avgRevolutionPeriod / (double) (avgdRevolutionPeriods - emptyRevolutionPeriods));
            for (int i = avgdRevolutionPeriods - 2; i > 0; i--) {
                oldRevolutionPeriods[i] = oldRevolutionPeriods[i - 1];
            }
            oldRevolutionPeriods[0] = revolutionPeriod;
            lastSample = currentMicros;
            virtualAngle = 0;
            lastVirtualAngle = -1;
            revolutionOffset = 0;
        }
        if (angle >= (90 - samplingThreshold) && angle <= (90 + samplingThreshold) && sampleCount == 2 &&
            currentMicros - lastSample >= 37500 && currentMicros - lastSample <= 375000) {
            if (isPaused) {
                isPaused = false;
            }
            revolutionPeriod = (currentMicros - lastSample) * 4;
            emptyRevolutionPeriods = 0;
            for (int i = 0; i < avgdRevolutionPeriods - 1; i++) {
                avgRevolutionPeriod += oldRevolutionPeriods[i];
                if (oldRevolutionPeriods[i] == 0) {
                    emptyRevolutionPeriods++;
                }
            }
            avgRevolutionPeriod =
                (unsigned long) round(avgRevolutionPeriod / (double) (avgdRevolutionPeriods - emptyRevolutionPeriods));
            for (int i = avgdRevolutionPeriods - 2; i > 0; i--) {
                oldRevolutionPeriods[i] = oldRevolutionPeriods[i - 1];
            }
            oldRevolutionPeriods[0] = revolutionPeriod;
            lastSample = currentMicros;
            virtualAngle = 0;
            lastVirtualAngle = -1;
            revolutionOffset = avgRevolutionPeriod * .75;
        }
        if (angle >= (180 - samplingThreshold) && angle <= (180 + samplingThreshold) &&
            ((sampleCount == 1 && currentMicros - lastSample >= 75000 && currentMicros - lastSample <= 750000) ||
             (sampleCount == 2 && currentMicros - lastSample >= 37500 && currentMicros - lastSample <= 375000))) {
            if (isPaused) {
                isPaused = false;
            }
            switch (sampleCount) {
                case 1:
                    revolutionPeriod = (currentMicros - lastSample) * 2;
                    break;
                case 2:
                    revolutionPeriod = (currentMicros - lastSample) * 4;
                    break;
            }
            emptyRevolutionPeriods = 0;
            for (int i = 0; i < avgdRevolutionPeriods - 1; i++) {
                avgRevolutionPeriod += oldRevolutionPeriods[i];
                if (oldRevolutionPeriods[i] == 0) {
                    emptyRevolutionPeriods++;
                }
            }
            avgRevolutionPeriod =
                (unsigned long) round(avgRevolutionPeriod / (double) (avgdRevolutionPeriods - emptyRevolutionPeriods));
            for (int i = avgdRevolutionPeriods - 2; i > 0; i--) {
                oldRevolutionPeriods[i] = oldRevolutionPeriods[i - 1];
            }
            oldRevolutionPeriods[0] = revolutionPeriod;
            lastSample = currentMicros;
            virtualAngle = 0;
            lastVirtualAngle = -1;
            revolutionOffset = avgRevolutionPeriod * .5;
        }
        if (angle >= (270 - samplingThreshold) && angle <= (270 + samplingThreshold) && sampleCount == 2 &&
            currentMicros - lastSample >= 37500 && currentMicros - lastSample <= 375000) {
            if (isPaused) {
                isPaused = false;
            }
            revolutionPeriod = (currentMicros - lastSample) * 4;
            emptyRevolutionPeriods = 0;
            for (int i = 0; i < avgdRevolutionPeriods - 1; i++) {
                avgRevolutionPeriod += oldRevolutionPeriods[i];
                if (oldRevolutionPeriods[i] == 0) {
                    emptyRevolutionPeriods++;
                }
            }
            avgRevolutionPeriod =
                (unsigned long) round(avgRevolutionPeriod / (double) (avgdRevolutionPeriods - emptyRevolutionPeriods));
            for (int i = avgdRevolutionPeriods - 2; i > 0; i--) {
                oldRevolutionPeriods[i] = oldRevolutionPeriods[i - 1];
            }
            oldRevolutionPeriods[0] = revolutionPeriod;
            lastSample = currentMicros;
            virtualAngle = 0;
            lastVirtualAngle = -1;
            revolutionOffset = avgRevolutionPeriod * .25;
        }
        // Pause display when user stops pedalling
        if ((sampleCount == 0 && currentMicros - lastSample > 1500000) ||
            (sampleCount == 1 && currentMicros - lastSample > 750000) ||
            (sampleCount == 2 && currentMicros - lastSample > 375000)) {
            if (!isPaused) {
                neopixels.clear();
                neopixels.show();
                for (int i = 0; i < avgdRevolutionPeriods - 1; i++) {
                    oldRevolutionPeriods[i] = 0;
                }
                isPaused = true;
            }
            lastSample = currentMicros;
        }
        if (!isPaused) {
            virtualAngle =
                360 -
                (((int) round(((currentMicros - lastSample) + revolutionOffset) / (avgRevolutionPeriod / 360.0))) %
                 360);
            // Animate through images if enabled
            if (displayMode >= STORAGE_SLOT_COUNT && currentMicros - lastSlotChange > animationInterval) {
                currentMemorySlot = (currentMemorySlot + 1) % 2;
                lastSlotChange = currentMicros;
            }
            // Display an angle of the image
            if (virtualAngle != lastVirtualAngle) {
                // Left side
                for (int i = 0; i < LED_COUNT; i++) {
                    byte r = images[currentMemorySlot][((virtualAngle % 360) * LED_COUNT) + i][0];
                    byte g = images[currentMemorySlot][((virtualAngle % 360) * LED_COUNT) + i][1];
                    byte b = images[currentMemorySlot][((virtualAngle % 360) * LED_COUNT) + i][2];
                    neopixels.setPixelColor(i, neopixels.Color(r, g, b));
                    r = images[currentMemorySlot][(((virtualAngle + strip1Position) % 360) * LED_COUNT) + i][0];
                    g = images[currentMemorySlot][(((virtualAngle + strip1Position) % 360) * LED_COUNT) + i][1];
                    b = images[currentMemorySlot][(((virtualAngle + strip1Position) % 360) * LED_COUNT) + i][2];
                    neopixels.setPixelColor(i + (LED_COUNT * 2), neopixels.Color(r, g, b));
                    r = images[currentMemorySlot][(((virtualAngle + strip2Position) % 360) * LED_COUNT) + i][0];
                    g = images[currentMemorySlot][(((virtualAngle + strip2Position) % 360) * LED_COUNT) + i][1];
                    b = images[currentMemorySlot][(((virtualAngle + strip2Position) % 360) * LED_COUNT) + i][2];
                    neopixels.setPixelColor(i + (LED_COUNT * 4), neopixels.Color(r, g, b));
                    r = images[currentMemorySlot][(((virtualAngle + strip3Position) % 360) * LED_COUNT) + i][0];
                    g = images[currentMemorySlot][(((virtualAngle + strip3Position) % 360) * LED_COUNT) + i][1];
                    b = images[currentMemorySlot][(((virtualAngle + strip3Position) % 360) * LED_COUNT) + i][2];
                    neopixels.setPixelColor(i + (LED_COUNT * 6), neopixels.Color(r, g, b));
                }
                // Right side
                for (int i = 0; i < LED_COUNT; i++) {
                    if (mirrorImage) {
                        // Display mirrored image (left becomes right, so both sides face in driving direction =>
                        // matching LED strips 100% identical, just show the same data)
                        byte r = images[currentMemorySlot][((virtualAngle % 360) * LED_COUNT) + i][0];
                        byte g = images[currentMemorySlot][((virtualAngle % 360) * LED_COUNT) + i][1];
                        byte b = images[currentMemorySlot][((virtualAngle % 360) * LED_COUNT) + i][2];
                        neopixels.setPixelColor(i + LED_COUNT, neopixels.Color(r, g, b));
                        r = images[currentMemorySlot][(((virtualAngle + strip1Position) % 360) * LED_COUNT) + i][0];
                        g = images[currentMemorySlot][(((virtualAngle + strip1Position) % 360) * LED_COUNT) + i][1];
                        b = images[currentMemorySlot][(((virtualAngle + strip1Position) % 360) * LED_COUNT) + i][2];
                        neopixels.setPixelColor(i + (LED_COUNT * 3), neopixels.Color(r, g, b));
                        r = images[currentMemorySlot][(((virtualAngle + strip2Position) % 360) * LED_COUNT) + i][0];
                        g = images[currentMemorySlot][(((virtualAngle + strip2Position) % 360) * LED_COUNT) + i][1];
                        b = images[currentMemorySlot][(((virtualAngle + strip2Position) % 360) * LED_COUNT) + i][2];
                        neopixels.setPixelColor(i + (LED_COUNT * 5), neopixels.Color(r, g, b));
                        r = images[currentMemorySlot][(((virtualAngle + strip3Position) % 360) * LED_COUNT) + i][0];
                        g = images[currentMemorySlot][(((virtualAngle + strip3Position) % 360) * LED_COUNT) + i][1];
                        b = images[currentMemorySlot][(((virtualAngle + strip3Position) % 360) * LED_COUNT) + i][2];
                        neopixels.setPixelColor(i + (LED_COUNT * 7), neopixels.Color(r, g, b));
                    } else {
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

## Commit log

2023-12-11 Uploaded already existing files.
    [18650-pack-mount-base.FCStd, 18650-pack-mount-base.stl, 18650-pack-mount-top.FCStd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]
2023-12-13 Implemented customizable LED strip position.
    [settings.csv]
2023-12-13 Implemented reverse rotation direction.
    [settings.csv]
2023-12-13 Added a test image by default and made sure settings changes are immediately applied.
    [image-0.csv]
2023-12-15 Implemented the first experimental support for LEDs on both side. Still needs to be tested.
    [settings.csv]
2023-12-16 Implemented customizable sampling threshold.
    [settings.csv]
2023-12-16 Implemented experimental image stability improvements.
    [settings.csv]
2023-12-17 Fixed a small logical error regarding the actual counterclockwise rotation of the wheel and the internal clockwise angle calculation.
    [bikebeamer.ino]
2023-12-17 Fixed the rotation detection and tweaked default settings.
    [settings.csv]
2023-12-17 Implemented sample smoothing and successfully tested the existing functionality.
2023-12-28 Reworked the README with an overview image and some MonkeyLight inspirations, added two sample images and created a storage backup of the prototype.
    [image-1.csv, image-2.csv, image-3.csv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]
2024-01-02 Designed a first prototype PCB and updated the README.
    [bikebeamer-v0.1.kicad_pcb, bikebeamer-v0.1.kicad_sch]
2024-01-02 Updated the mounting visualisation and code to accomodate the new PCB.
2024-01-03 Tweaked the mounting visualisation to reflect the new control board and battery pack locations.
2024-01-04 Added a note clarifying the indexing to README and removed storage backup.
    [image-1.csv, image-2.csv, image-3.csv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]
2024-01-04 Removed the strip 0 position and reverse direction option, since both become obsolete with the new PCB.
    [settings.csv]
2024-01-13 Removed the outdated CAD files and added some build instructions to the README.
    [18650-pack-mount-base.FCStd, 18650-pack-mount-base.stl, 18650-pack-mount-top.FCStd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]
2024-01-15 Designed a first prototype case.
    [assembly.FCStd, case-bottom.FCStd, case-bottom.stl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]
2024-01-16 Fixed some minor design flaws I noticed after printing.
    [assembly.FCStd, case-bottom.FCStd, case-bottom.stl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]
2024-01-16 Added the case to the documentation.
2024-01-17 Fxied a missing feature due to invalid dependencies.
    [assembly.FCStd, case-bottom.FCStd, case-bottom.stl]
2024-01-18 Fixed another CAD dependency issue.
    [assembly.FCStd, case-bottom.FCStd, case-bottom.stl]
2024-01-20 Added a picture of the encased boards.
2024-01-24 Moved the LED strip pads 1mm further apart.
    [bikebeamer-v0.2.kicad_pcb, bikebeamer-v0.2.kicad_sch]
2024-01-24 Updated the case with grooves for rubber bands to keep the top in place.
    [assembly.FCStd, case-bottom.FCStd, case-bottom.stl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]
2024-01-27 Fixed animation dropouts at high speeds.
    [bikebeamer.ino]
2024-01-27 Added some pictures of the encased boards being mounted.
2024-01-28 Implemented user-changable revolution period averaging.
    [settings.csv]
2024-01-28 Updated default settings for higher image stability and brightness.
    [settings.csv]
2024-01-28 Added some tweaks to the revolution period averaging to make sure that it gets reset on cycling pauses and only takes non-zero measurements into account when beginning to drive again.
    [bikebeamer.ino]
2024-02-17 Slightly increased case top tolerances.
    [assembly.FCStd, case-top.FCStd, case-top.stl]
2024-02-24 Implemented associative names for images and loading settings to UI.
    [images.csv, settings.csv]
2024-02-24 Finished reworking the API.
    [bikebeamer.ino]
2024-12-15 docs: dependencies for Arduino IDE 2.x and latest ESP32 core libs
